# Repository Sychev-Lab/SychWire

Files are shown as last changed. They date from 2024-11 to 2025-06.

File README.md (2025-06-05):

# SychWire

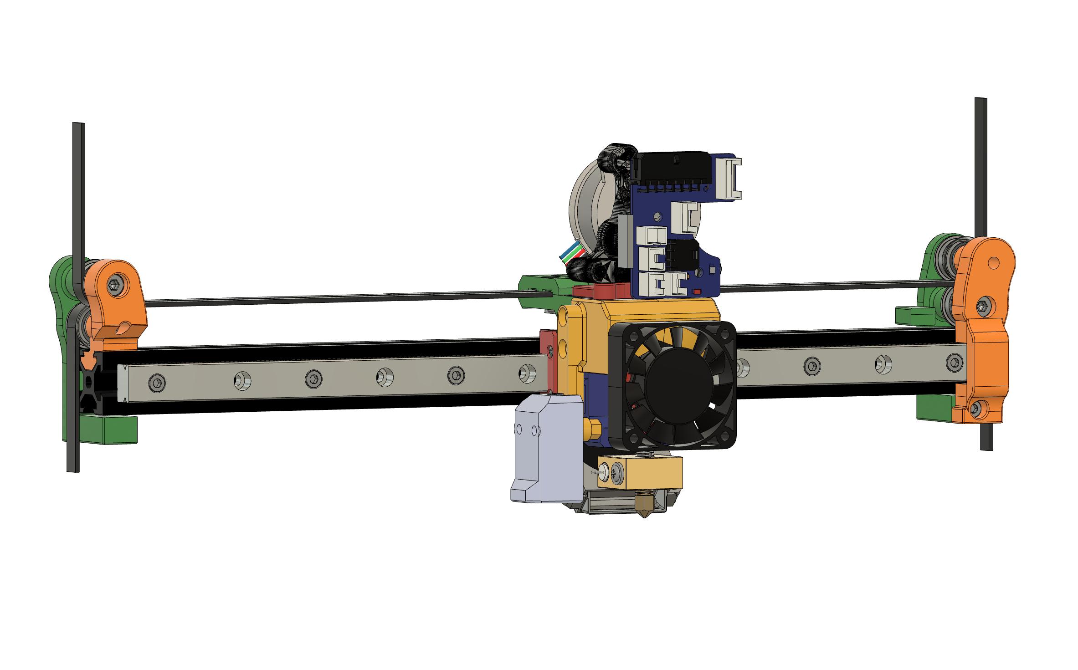
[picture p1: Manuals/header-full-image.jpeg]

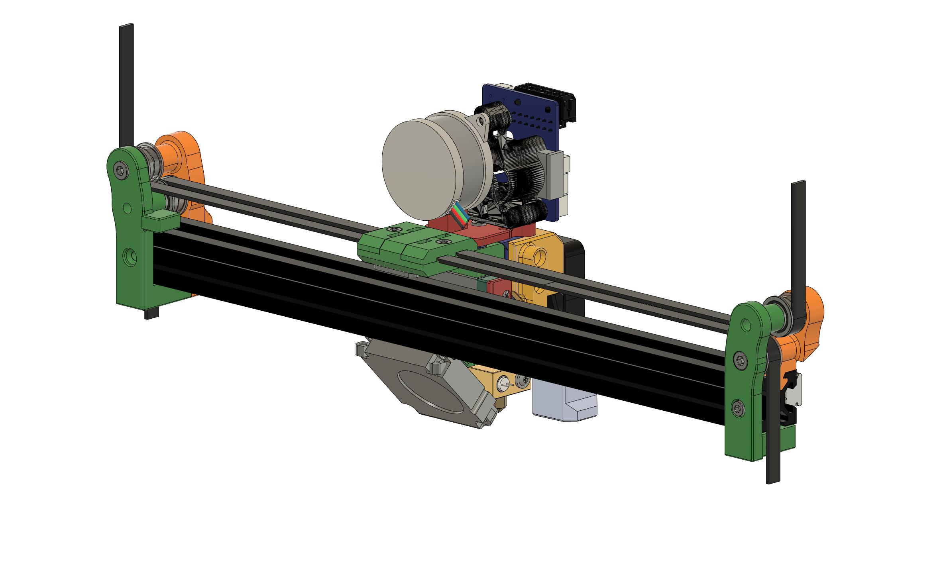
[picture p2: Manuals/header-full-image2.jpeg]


This is a custom modification by the author. From a Voron SwitchWire 3D printer.
Original Link project: https://github.com/VoronDesign/Voron-Switchwire

It is based on CORE XZ.

Therefore this repository will only have new elements modified by the author.
The changes have been made to facilitate the change of the head and lighter X-axis parts while maintaining the functionality and allowing the head to move up to the edges of the bed.
to the edges of the bed. In base I have used Ender 3 Pro which has a 235x235mm bed.

In the mod I use:

* Sherpa with a modified part to place the PCB board in front of the head (Mellow Voron 2,4 R2 Trident Stealthburner)
* Sherpa used with motor LDO Nema 14 8T
* Use of reiles in the three axes X, Y and Z.
* The X-axis has new lateral supports, which are more flexible and more leggy.
    * Left side:
        * It is mounted with two M3x10 screws and fastened with two M3 nuts that are inserted into the rail.
        * It is bolted with a dowel screw, bearings and turecas in between.
        * The front piece is inserted into the rail.
    * Right side:
        * It is mounted with two M3x10 screws and fastened with two M3 nuts that are inserted into the rail.
        * It is bolted with a dowel screw, bearings and turecas in between.
        * The front piece is screwed to the rear piece with a brass isert.
* The belt is used GT2 of 6mm width and 2mm pitch. It is passed over the top of the X-axis and fastened with a belt tensioner on the head piece.
* Head set:
    * Standard CR10 hotend is used.
    * It has a 2020 front fan (comes in Ender).
    * It has a 4020 layer fan (comes in Ender).
    * In this version I use Eddy Coil that connects with USB to RPi Zero W.

* Software
    * Klipper (se adjuntan configuraciones)

---

# Head set

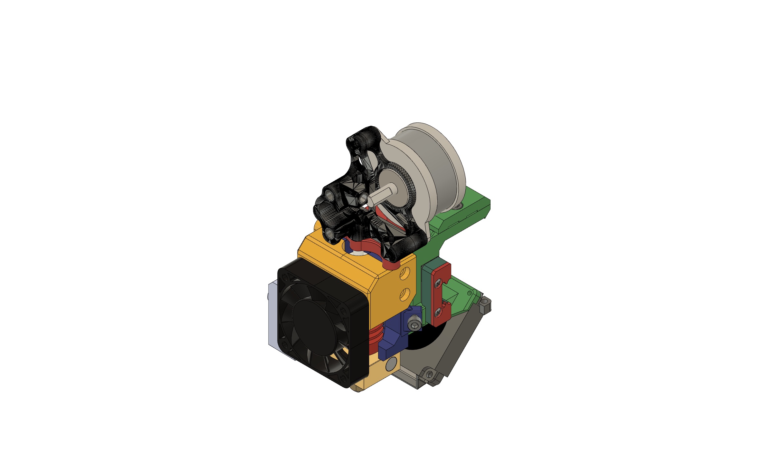
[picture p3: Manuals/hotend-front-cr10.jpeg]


It consists of a fixed part that is part of the base and is screwed to the rail reel with four M3x10 screws.
In which the stopend is screwed at the rear, it has to be placed before screwing the base. The same is true for the fan layer, which is screwed on with two screws that come as standard.

Once screwed, the straps can be mounted and fastened with its corresponding screw on each side.

On top of the base, the rest of the elements are fitted: top cover with Eddy Coil, fan, Hotend, Sherpa and PCB board.

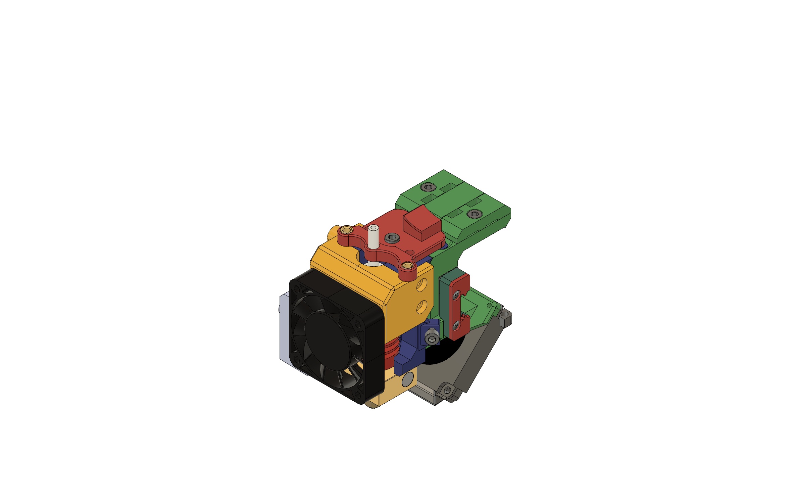
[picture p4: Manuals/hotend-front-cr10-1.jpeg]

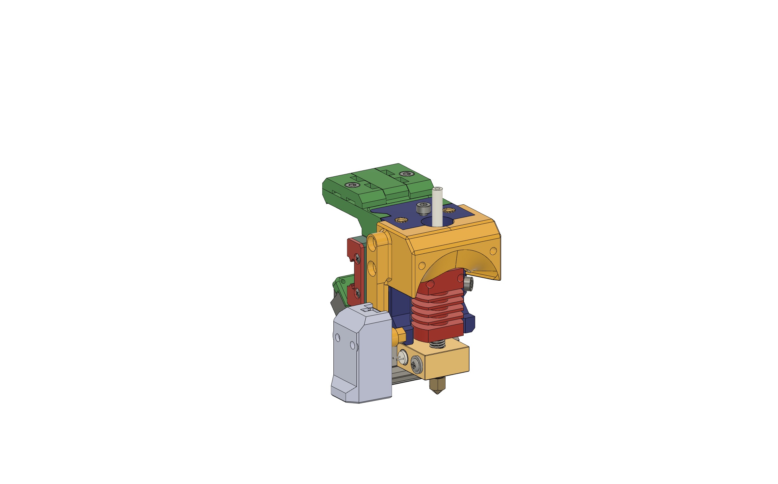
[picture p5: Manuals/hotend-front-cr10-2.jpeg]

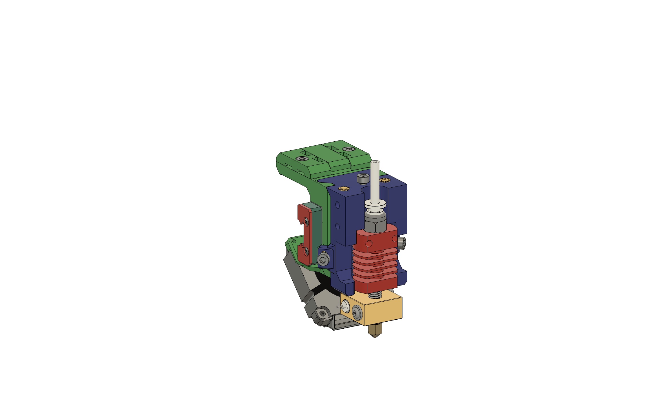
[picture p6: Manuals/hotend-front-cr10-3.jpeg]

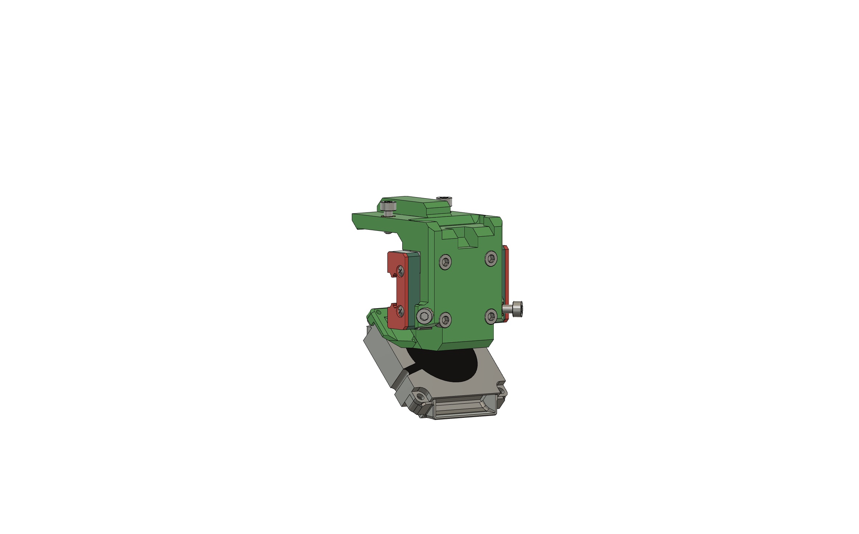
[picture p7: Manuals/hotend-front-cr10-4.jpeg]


---

## Star History

Star History Chart (https://star-history.com/#Sychev-Lab/SychWire&Date)

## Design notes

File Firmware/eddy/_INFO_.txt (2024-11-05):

#skr mini e3 v3.1
#chipset: STM32 STM32G0B1 ret6 8KiB 8mhz
#comunication: serial pa3/pa2
#baud: 250000
#cristal 8

#baud: 115200
#ender standar lcd: esd4k cr10

#in klipper folder: `make claen`, `make menuconfig`, `make`
#after compile: `./scripts/flash-sdcard.sh /dev/ttyACM0 btt-skr-mini-e3-v3`

# Klipper Shake&Tune Module
#https://github.com/Frix-x/klippain-shaketune?tab=readme-ov-file

# Klipper Linear Movement Vibrations Analysis
#https://github.com/worksasintended/klipper_linear_movement_analysis

# Pressure advance calibration
#https://github.com/Frix-x/klippain/blob/main/docs/features/pa_calibration.md

# Flow calibration
#https://github.com/Frix-x/klippain/blob/main/docs/features/flow_calibration.md

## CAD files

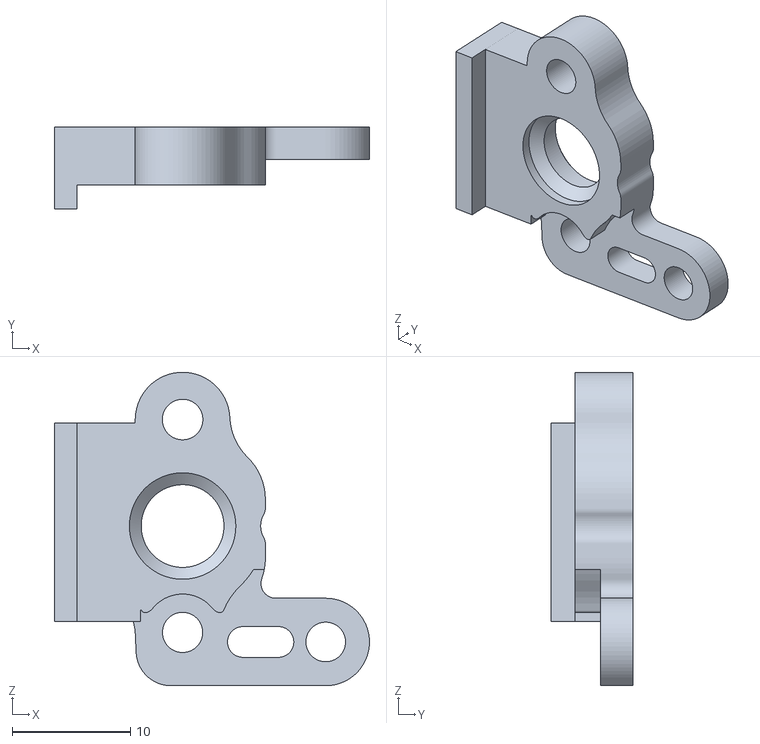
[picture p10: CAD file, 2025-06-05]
STL/Head/pcb-sherpa-support.stl
26.6 x 6.90 x 26.5

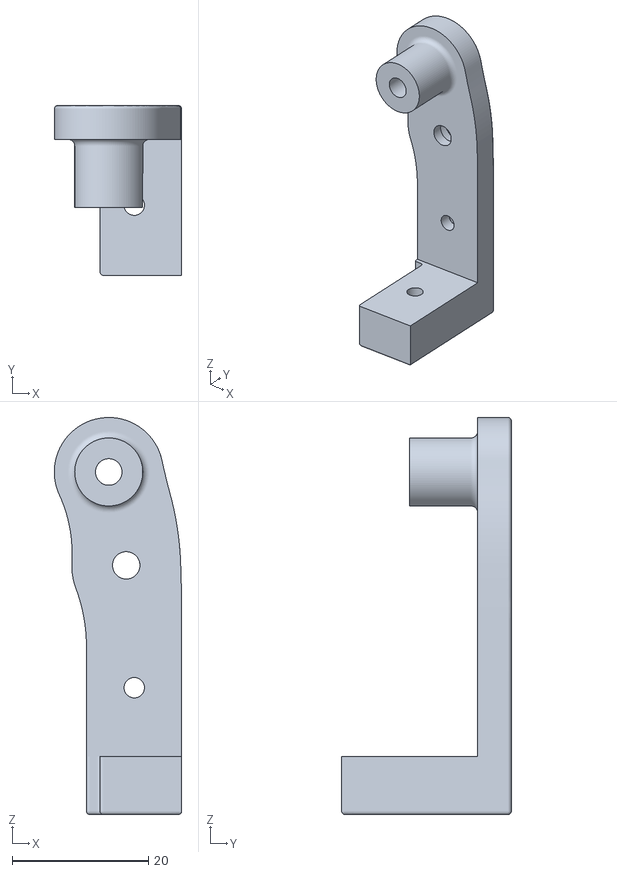
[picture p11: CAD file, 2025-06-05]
STL/x-axies/Left/left-back.stl
18.7 x 25.0 x 58.4

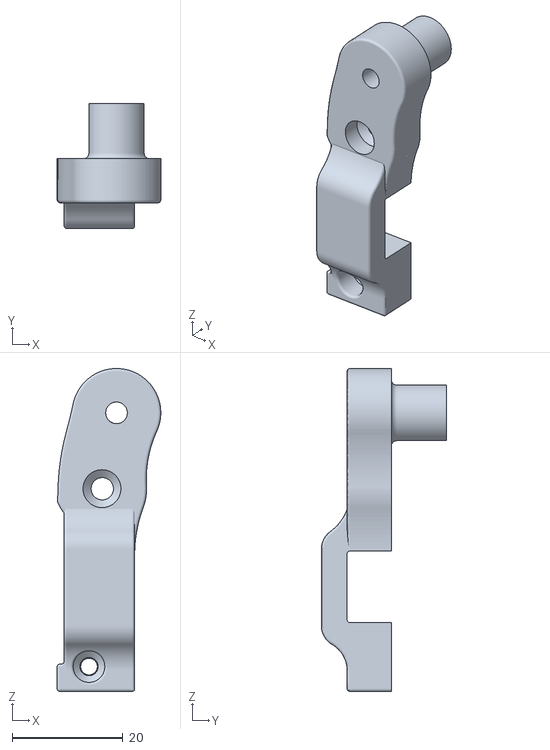
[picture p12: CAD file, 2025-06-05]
STL/x-axies/Right/front right.stl
18.7 x 22.7 x 58.4

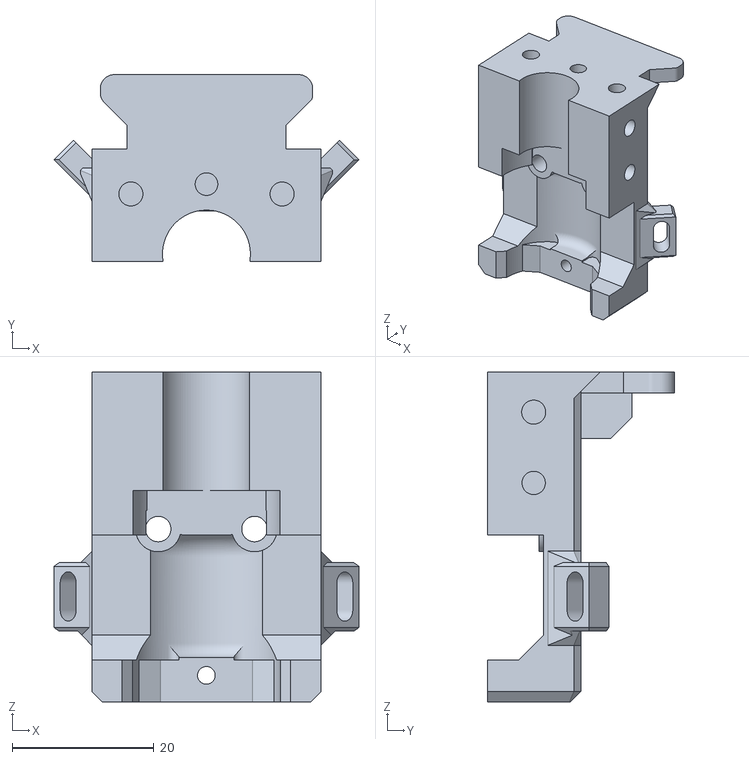
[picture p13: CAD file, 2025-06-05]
STL/Head/hotend-back.stl
43.1 x 26.4 x 46.6

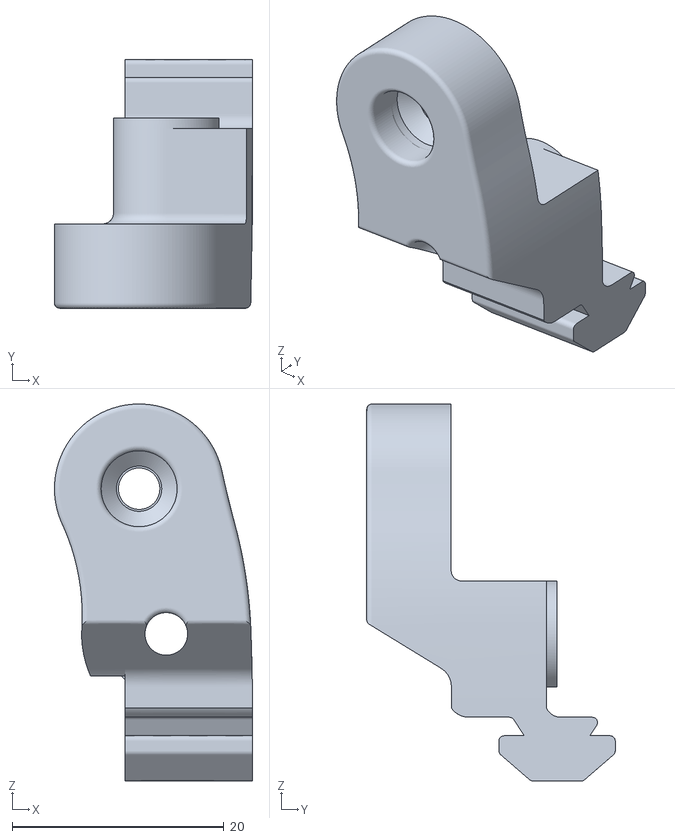
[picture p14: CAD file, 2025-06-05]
STL/x-axies/Left/left-front.stl
18.7 x 23.5 x 35.6

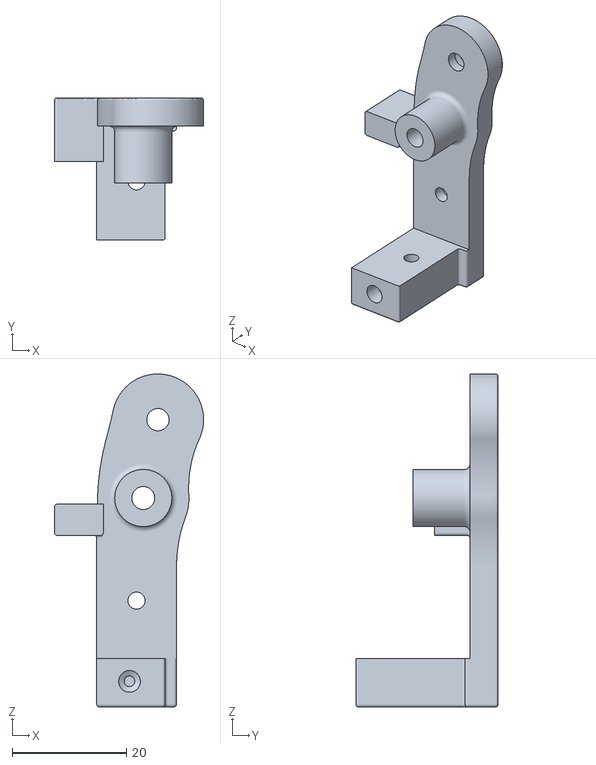
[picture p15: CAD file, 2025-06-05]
STL/x-axies/Right/right-back.stl
26.1 x 25.0 x 58.4

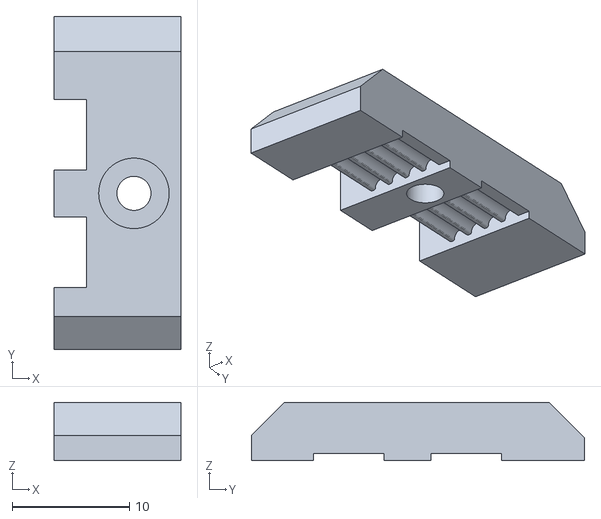
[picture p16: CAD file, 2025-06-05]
STL/Head/base-gt2-right.stl
10.8 x 28.4 x 4.97

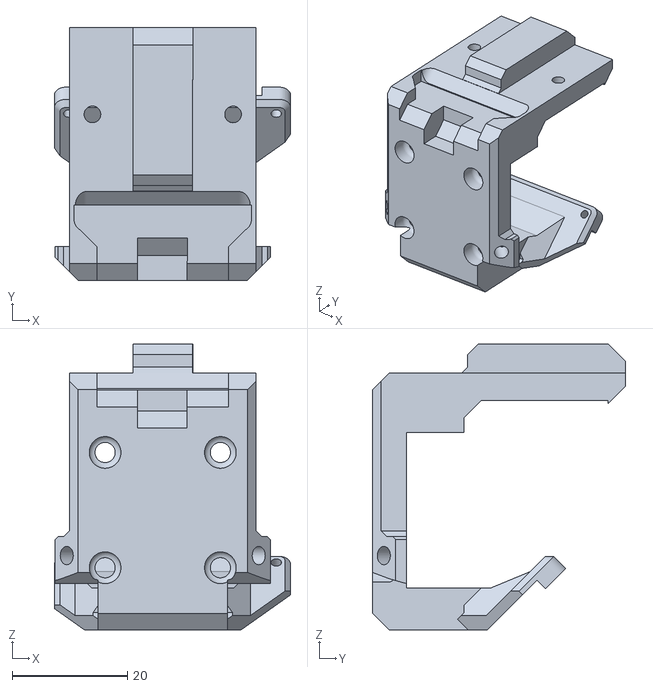
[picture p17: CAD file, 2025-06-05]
STL/Head/base-with-4010-fan-support.stl
41.0 x 43.9 x 49.6

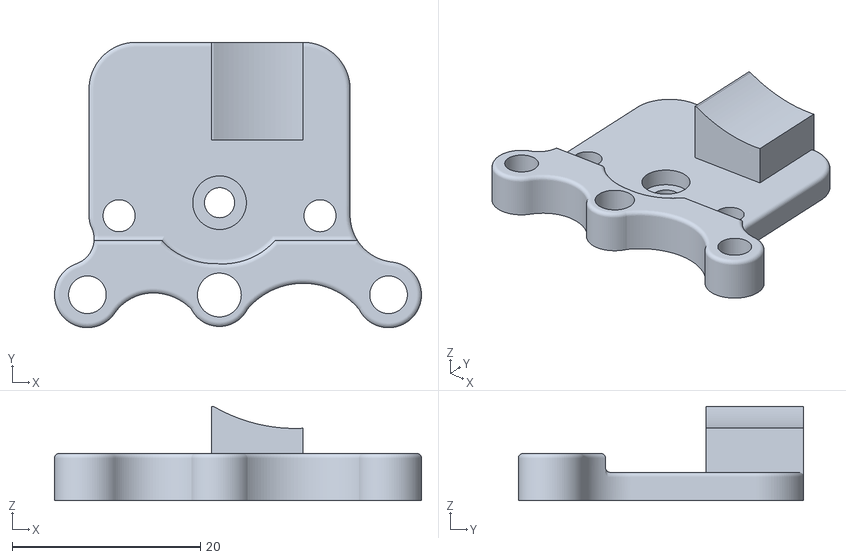
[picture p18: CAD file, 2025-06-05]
STL/Head/sherpa adaptador-v2.stl
39.0 x 30.3 x 10.0

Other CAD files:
STL/Head/base-gt2-left.stl

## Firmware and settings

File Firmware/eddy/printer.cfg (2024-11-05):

# This file contains common pin mappings for the BIGTREETECH SKR mini
# E3 v3.0. To use this config, the firmware should be compiled for the
# STM32G0B1 with a "8KiB bootloader" and USB communication.

# The "make flash" command does not work on the SKR mini E3. Instead,
# after running "make", copy the generated "out/klipper.bin" file to a
# file named "firmware.bin" on an SD card and then restart the SKR
# mini E3 with that SD card.

# See docs/Config_Reference.md for a description of parameters.

# BED MESH
# X MAX = 250 232 LIMIT
# Y MAX = 250 213 LIMIT
# Z MAX = 150(save) 175 LIMIT
#
# X CENTER 169
# Y CENTER 197

[include mainsail.cfg]
[include macros/*.cfg]

#[include host_display_menu.cfg]
#[host_ip]

#[include adxl345.cfg] # Comment this out when you disconnect the accelerometer
[include inputShaper.cfg] # Comment when use adxl345 accelerometer

#Legacy Adaptive Meshing
[include KAMP_Settings.cfg]
#[include Adaptive_Mesh_legacy.cfg]

[include K-ShakeTune/*.cfg]

[exclude_object]

[mcu]
serial: /dev/ttyAMA0
restart_method: command

[printer]
kinematics: corexz
max_velocity: 300
max_accel: 4000
max_z_velocity: 8
max_z_accel: 120

# ---------------------

[bed_mesh]
speed: 200
horizontal_move_z: 2
algorithm: bicubic
mesh_min: 20, 10
mesh_max: 189, 190
probe_count: 10, 10
scan_overshoot: 8

# ---------------------

[mcu eddy]
serial: /dev/serial/by-id/usb-Klipper_rp2040_504434031023951C-if00
restart_method: command

[temperature_sensor btt_eddy_mcu]
sensor_type: temperature_mcu # Sets the type of sensor for Klipper to read
sensor_mcu: eddy # Sets the MCU of the eddy probe tempereature sensor
min_temp: 10 # Sets the minimum tempereature for eddys tempereature sensor to operate
max_temp: 100 # Sets the maximum tempereature for eddys tempereature sensor to operate

[probe_eddy_current btt_eddy]
sensor_type: ldc1612
#z_offset: 2
#i2c_address:
i2c_mcu: eddy  # This value is good for the Eddy USB but would need to be adjusted for the Eddy Coil according to the MCU you have used.
i2c_bus: i2c0f # This value is good for the Eddy USB but would need to be adjusted for the Eddy Coil according to the I2C bus you have used.
# Measure the offsets below using the method described here: https://www.klipper3d.org/Probe_Calibrate.html#calibrating-probe-x-and-y-offsets
# For a standard Voron stealthburner X carriage mount there should be no need to change the defaults below.
x_offset: -27
y_offset: 0

# This section is only relevant for Eddy USB. Comment it out for Eddy Coil.
[temperature_probe btt_eddy]
sensor_type: Generic 3950
sensor_pin: eddy:gpio26
horizontal_move_z: 2

# ---------------------

[safe_z_home]
home_xy_position: 124, 118 # center nozzle
z_hop: 10
z_hop_speed: 25
speed: 200

[screws_tilt_adjust]
screw1: 60, 30
screw1_name: fl del. izq 1 
screw2: 230, 30
screw2_name: fr del. der 2
screw3: 230, 197
screw3_name: rr det. der 3
screw4: 60, 197
screw4_name: rl det. izq 4
horizontal_move_z: 10
speed: 250
screw_thread: CW-M3

# ---------------------

[stepper_x]
step_pin: PB13
dir_pin: PB12
enable_pin: !PB14
microsteps: 32
full_steps_per_rotation: 200
rotation_distance: 40
endstop_pin: ^PC0
position_min: 0
position_max: 232
position_endstop: 232
homing_speed: 100
homing_positive_dir: true

[tmc2209 stepper_x]
uart_pin: PC11
tx_pin: PC10
uart_address: 0
run_current: 0.580 # new - may need changing

[stepper_z]
step_pin: PB0
dir_pin: PC5
enable_pin: !PB1
microsteps: 32
full_steps_per_rotation: 200
rotation_distance: 40
endstop_pin: probe:z_virtual_endstop #^PC2
position_min: -6
position_max: 150
homing_speed: 100

[tmc2209 stepper_z]
uart_pin: PC11
tx_pin: PC10
uart_address: 1
run_current: 0.580
interpolate: False

# ---------------------

[stepper_y]
step_pin: PB10
dir_pin: PB2
enable_pin: !PB11
microsteps: 32
full_steps_per_rotation: 200
rotation_distance: 40
endstop_pin: ^PC1
position_endstop: 0
position_max: 213
homing_speed: 100
second_homing_speed: 50

[tmc2209 stepper_y]
uart_pin: PC11
tx_pin: PC10
uart_address: 2
run_current: 0.580
interpolate: False

# ---------------------

[extruder]
step_pin: PB3
dir_pin: !PB4
enable_pin: !PD1
microsteps: 32
#rotation_distance: 33.500 #<- este es anterior de ender3
rotation_distance: 4.637 # LDO-36STH20-1004AHG
max_extrude_only_distance: 500 # LDO-36STH20-1004AHG
max_extrude_only_velocity: 120 # LDO-36STH20-1004AHG
nozzle_diameter: 0.400
filament_diameter: 1.750
heater_pin: PC8
sensor_pin: PA0
min_extrude_temp: 9
max_extrude_cross_section: 2
max_extrude_only_distance: 100
#pressure_advance LDO-36STH20-1004AHG
#pressure_advance:
#
#control: pid
#[cr10 ender sensor]
#sensor_type: EPCOS 100K B57560G104F
#min_temp: 0
#max_temp: 250
#pid_Kp: 21.527
#pid_Ki: 1.063
#pid_Kd: 108.982
#pressure_advance: 0.44
#---
#pid_Kp: 54.027
#pid_Ki: 0.770
#pid_Kd: 948.182
#---
# PREASSURE ADVANCE
# PLA acc 4000 = 0.4912
# PLA acc 500 = 1.006
# ABS acc 500 = 0.1075
# 12.83*0,020 https://www.klipper3d.org/Pressure_Advance.html#tuning-pressure-advance
#pressure_advance: 0.29509 # default ender klipper
pressure_advance: 0.0275 # PLA+
#pressure_advance: 0.1075 # ABS
pressure_advance_smooth_time: 0.040
#---
sensor_type: ATC Semitec 104GT-2
pullup_resistor: 4267
min_temp: -273.15
max_temp: 300

[tmc2209 extruder]
uart_pin: PC11
tx_pin: PC10
uart_address: 3
run_current: 0.650
stealthchop_threshold: 999999
interpolate: False

# ---------------------

[heater_bed]
heater_pin: PC9
sensor_type: ATC Semitec 104GT-2
sensor_pin: PC4
min_temp: 0
max_temp: 130

#https://jat.mn/how-to-controlling-the-mcu-fan-via-mcu-temperature-klipper/
#https://github.com/zellneralex/klipper_config/blob/master/fan.cfg

#Part cooling fan FAN0
[fan]
pin: PC6

#pice fan FAN1
[heater_fan hotend_fan]
pin: PB15
heater: extruder
heater_temp: 50.0

#mother board #FAN2 pb15
[controller_fan electronic_enclosure_fan]
pin: PC7
idle_timeout: 60

[verify_heater extruder]
#max_error: 120
#   The maximum "cumulative temperature error" before raising an
#   error. Smaller values result in stricter checking and larger
#   values allow for more time before an error is reported.
#   Specifically, the temperature is inspected once a second and if it
#   is close to the target temperature then an internal "error
#   counter" is reset; otherwise, if the temperature is below the
#   target range then the counter is increased by the amount the
#   reported temperature differs from that range. Should the counter
#   exceed this "max_error" then an error is raised. The default is
#   120.
check_gain_time: 50
#   This controls heater verification during initial heating. Smaller
#   values result in stricter checking and larger values allow for
#   more time before an error is reported. Specifically, during
#   initial heating, as long as the heater increases in temperature
#   within this time frame (specified in seconds) then the internal
#   "error counter" is reset. The default is 20 seconds for extruders
#   and 60 seconds for heater_bed.
#hysteresis: 5
#   The maximum temperature difference (in Celsius) to a target
#   temperature that is considered in range of the target. This
#   controls the max_error range check. It is rare to customize this
#   value. The default is 5.
#heating_gain: 2
#   The minimum temperature (in Celsius) that the heater must increase
#   by during the check_gain_time check. It is rare to customize this
#   value. The default is 2.

# ---------------------

#[firmware_retraction]
#retract_length: 0.6
#retract_speed: 40
#unretract_extra_length: 0
#unretract_speed: 40

# ---------------------

[board_pins]
aliases:
	# EXP1 header
	EXP1_1=PB5,  EXP1_3=PA9,   EXP1_5=PA10, EXP1_7=PB8, EXP1_9=<GND>,
	EXP1_2=PA15, EXP1_4=<RST>, EXP1_6=PB9,  EXP1_8=PD6, EXP1_10=<5V>

# See the sample-lcd.cfg file for definitions of common LCD displays.

######################################################################
# 128x64 Full Graphic Creality CR10 / ENDER 3 stockdisplay
######################################################################

# This section is used for a Creality "12864" display with a single
# ribbon cable between the display's EXP3 plug and the
# micro-controller board's EXP1 connector.

#[display]
#lcd_type: st7920
#cs_pin: EXP1_7
#sclk_pin: EXP1_6
#sid_pin: EXP1_8
#encoder_pins: ^EXP1_5, ^EXP1_3
#click_pin: ^!EXP1_2

#speaker
#[output_pin beeper]
#pin: EXP1_1

# ---------------------

#temp pcb pks motherboard
[temperature_sensor MCU]
sensor_type: temperature_mcu
min_temp: 0
max_temp: 100

#temp on rpi
[temperature_sensor Pi]
sensor_type: temperature_host
min_temp: 0
max_temp: 80

# ---------------------

[temperature_sensor tmc2209_stepper_x]
sensor_type: temperature_host
min_temp: 10
max_temp: 100

[temperature_sensor tmc2209_stepper_y]
sensor_type: temperature_host
min_temp: 10
max_temp: 100

[temperature_sensor tmc2209_stepper_z]
sensor_type: temperature_host
min_temp: 10
max_temp: 100

[temperature_sensor extruder_stepper]
sensor_type: temperature_host
min_temp: 10
max_temp: 100

# ---------------------
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

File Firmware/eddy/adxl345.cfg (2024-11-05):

# █▀ █▄█ █▀▀ █░█ █▀▀ █░█
# ▄█ ░█░ █▄▄ █▀█ ██▄ ▀▄▀
# 
# Author: <Anton Sychev> (anton at sychev dot xyz) 
# host_display_menu.cfg (c) 2023 
# Created:  2023-07-15 02:06:08 
# Desc: Accelerometer adxl345
# Git: https://github.com/klich3/klipper---adxl345-skr-mini-e3-v3.0
# Docs: 
# - https://www.klipper3d.org/Measuring_Resonances.html

# - https://www.engineersgarage.com/adxl345-accelerometer-raspberry-pi-i2c/
# - https://www.klipper3d.org/Measuring_Resonances.html
# - https://www.youtube.com/watch?v=kg_jYL7ksEc&list=WL&index=108
# - https://www.obico.io/blog/klipper-input-shaping-ender-3/

# - https://os.ratrig.com/assets/files/skr-mini-e3-30-wiring-5ed9982d5a1c62e9f30c37b29a2e5571.svg
# - https://os.ratrig.com/docs/boards/btt/skr-mini-e3-30/
# - connectar todos pero sin vcc y gnd una vez se resetea se vulve a conectar
# 1) command MEASURE_AXES_NOISE Should be somewhere in the range of ~1-100
# 2) TEST_RESONANCES AXIS=X
# 3) TEST_RESONANCES AXIS=Y
# 4) ~/klipper/scripts/calibrate_shaper.py /tmp/resonances_x_*.csv -o /tmp/shaper_calibrate_x.png
#    ~/klipper/scripts/calibrate_shaper.py /tmp/resonances_y_*.csv -o /tmp/shaper_calibrate_y.png
#------------------

#i2c
#command for detect device
#sudo i2cdetect -y 1 
#/dev/i2c-1

#pins rpi zero 1.1
# 1 - vcc 3v3   | 2 - 
# 3 - sda gpio2 | 4 -
# 5 - scl gpio3 | 6 - gnd

#Correct result
#     0  1  2  3  4  5  6  7  8  9  a  b  c  d  e  f
#00:                         -- -- -- -- -- -- -- -- 
#10: -- -- -- -- -- -- -- -- -- -- -- -- -- -- -- -- 
#20: -- -- -- -- -- -- -- -- -- -- -- -- -- -- -- -- 
#30: -- -- -- -- -- -- -- -- -- -- -- -- -- -- -- -- 
#40: -- -- -- -- -- -- -- -- -- -- -- -- -- -- -- -- 
#50: -- -- -- 53 -- -- -- -- -- -- -- -- -- -- -- -- 
#60: -- -- -- -- -- -- -- -- -- -- -- -- -- -- -- -- 
#70: -- -- -- -- -- -- -- --  

#------------------

#RPI zero

#[mcu rpi]
#serial: /tmp/klipper_host_mcu #default

#[adxl345]
#cs_pin: rpi:None
#cs_pin: arduino_nano_adxl:PB2


#----

#arduino
#[mcu arduino_nano_adxl]
  #serial: /dev/ttyUSB0 
  #serial: /dev/serial/by-id/usb-1a86_USB2.0-Serial-if00-port0
   # Be sure to change serial address below as per output of 'ls /dev/serial/by-id/*'

#----

#Direct on board
#SRK mini v3.1 spi 1

# 1 -          | 2 -
# 3 - NSS      | 4 - CLK
# 5 - MOSI     | 6 - MISO
# 7 - 3.3v vcc | 8 - GND

#SRK mini v3.1 i/o SPI2

# vcc + gnd connect to SPI1 3.3v

#  ·  |  ·  |  ·  |  ·  |  ·  
# PD0 | PD2 | PD3 | PD4 | PD5 
# cs  | scl | sda | sd0 |  x
# NSS | CLK | MOSI| MISO|  x

#[adxl345]
##axes_map: -x,-y,z
#cs_pin: PD0
#spi_software_miso_pin: PD4
#spi_software_sclk_pin: PD2
#spi_software_mosi_pin: PD3


#SPI
#cs_pin: PD9
#spi_bus: spi1


#USB rpi mini
[mcu PIS]
serial: /dev/serial/by-id/usb-Klipper_rp2040_E6612C771F4DC52B-if00

[adxl345]
cs_pin: PIS:gpio13
spi_software_miso_pin: PIS:gpio12
spi_software_sclk_pin: PIS:gpio10
spi_software_mosi_pin: PIS:gpio11
#axes_map: x,-z,y


[resonance_tester]
accel_chip: adxl345
#accel_per_hz: 50
min_freq: 30
#max_freq: 43
#max_freq: 25
max_smoothing: 0.25
probe_points: 125,125,20 #85,105,20 


[gcode_macro ADXL_QUERY]
gcode:
  ACCELEROMETER_QUERY

[gcode_macro ADXL_NOISE]
gcode:
  MEASURE_AXES_NOISE

[gcode_macro ADXL_RES_Y]
gcode:
  TEST_RESONANCES AXIS=Y

[gcode_macro ADXL_RES_X]
gcode:
  TEST_RESONANCES AXIS=X

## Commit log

2024-08-21 Added STL models Added Firmware files, printer config for Skr Mini e3 v3.1
    [3DTOUCH.cfg, 4010-fender-deflector.stl, 4010-spacer-l.stl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]
2024-11-05 feature: actualizacion de soporte, paso a tornillos frontales mejor acceso feature: added klipper eddy configs update: modified front cover update: the base has been updated
    [2020_MGN12_guide_x2.stl, 3030_MGN12_guide_x2.stl, 3DTOUCH.cfg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]
2025-06-05 added: configurations simplify: models
    [2020_MGN12_guide_x2.stl, 3030_MGN12_guide_x2.stl, 4010-fender-deflector.stl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]
2025-06-05 update: description on readme update: images added: cad step files
